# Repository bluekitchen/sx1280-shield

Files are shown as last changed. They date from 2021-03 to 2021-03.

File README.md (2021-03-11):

# SX1280 Breakout Board in Arduino Form-Factor

This is a breakout board for the SX1280 in Arduino form-factor to use with e.g. STM32 Nucleo Dev Boards or similar. It uses the [E28-2G4M12S module from EBYTE](https://www.ebyte.com/en/new-view-info.aspx?id=297), which is readily available from AliExpress or Banggod. 

## Motivation

The official SX1280 shield (SX1280RF1ZHP) from the Semtech's [SX1280DVK1ZHP](https://www.semtech.com/products/wireless-rf/24-ghz-transceivers/sx1280dvk1zhp) or [SX1280ED1ZHP](https://www.semtech.com/products/wireless-rf/lora-transceivers/sx1280ed1zhp) development kits have resistors in the SPI lines, which limit the SPI speed to about 5 Mhz. 

While SPI speed is not relevant for LoRa operations, implementing Bluetooth Low Energy requires to transfer data packets to/from the SX1280 quickly, which is easier to achieve with the max SPI speed of 18 Mhz. This breakout board was created to avoid replacing the resistors with 0 Ohm ones on the official shield and to allow the full 18 Mhz SPI speed.

## Usage

Signal | Arduino | Debug connector
-------|---------|----------------
3V3    |  3V3    | 
GND    |  GND    |   1
NSS    |  D7     |   2
SCK    |  SCK    |   3
MOSI   |  MOSI   |   4
MISO   |  MISO   |   5
BUSY   |  D3     |   6
DIO1   |  D5     |   7
DIO2   |         |   8
DIO3   |         |   9
nReset |  A0     |  10

All signals are provided at the J1 debug connector to hook up a logic analyzer.

The SX1280 can map various IRQ requests on the DIO1-3 pins. DIO1 is pre-assigned in this shield, while the DIO2 and DIO3 can be connected via jumper J2 to other GPIO pins if needed. 

Please note: The SX1280 is not 5V tolerant.

## References
- [SX1280 Product Page](https://www.semtech.com/products/wireless-rf/24-ghz-transceivers/sx1280)
- [SX1280 Datahsheet](https://semtech.my.salesforce.com/sfc/p/E0000000JelG/a/2R000000HoCW/8EVYKPLcthcKCB_cKzApAc6Xf6tAHtn9.UKcOh7SNmg)
- [28-2G4M12S Datasheet](https://www.ebyte.com/en/downpdf.aspx?id=286)

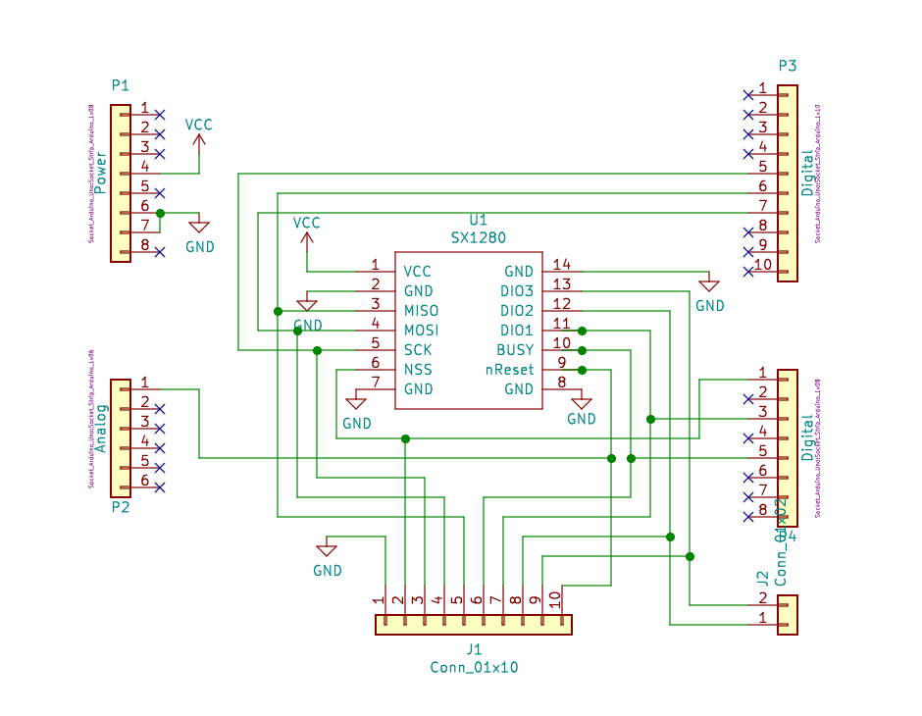
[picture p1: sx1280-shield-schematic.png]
Schematic

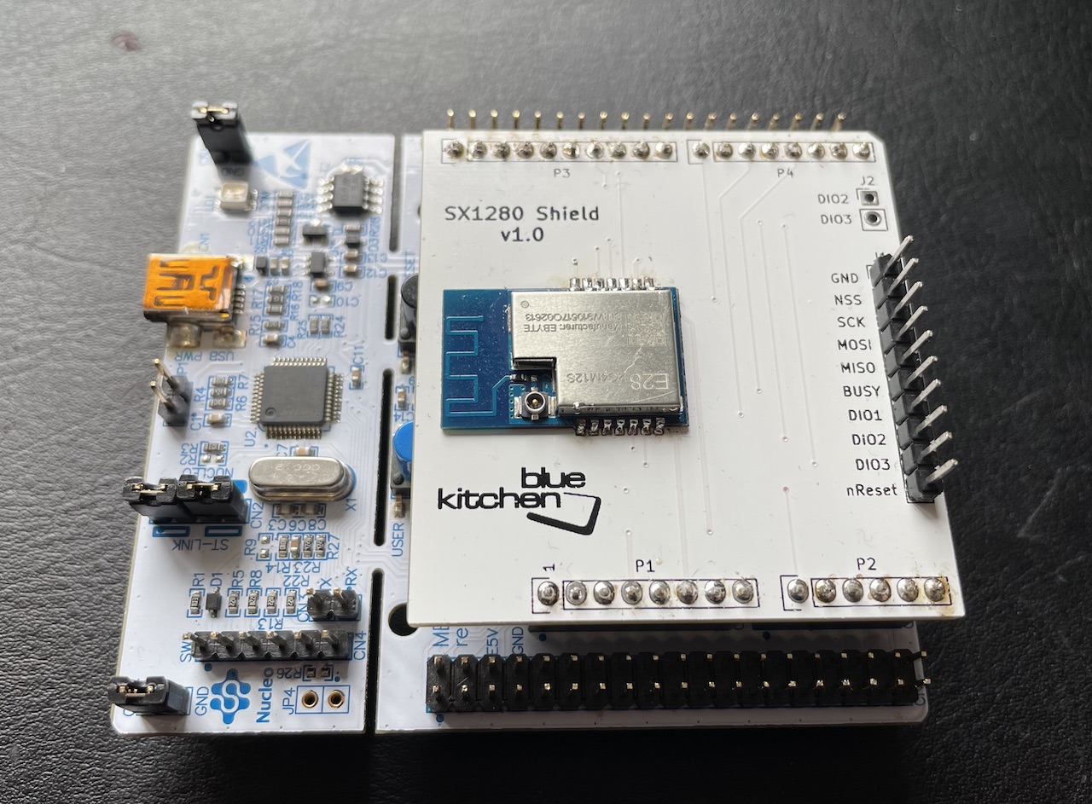
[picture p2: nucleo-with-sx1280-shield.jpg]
STM32 L476RG Nucleo with SX1280 Shield


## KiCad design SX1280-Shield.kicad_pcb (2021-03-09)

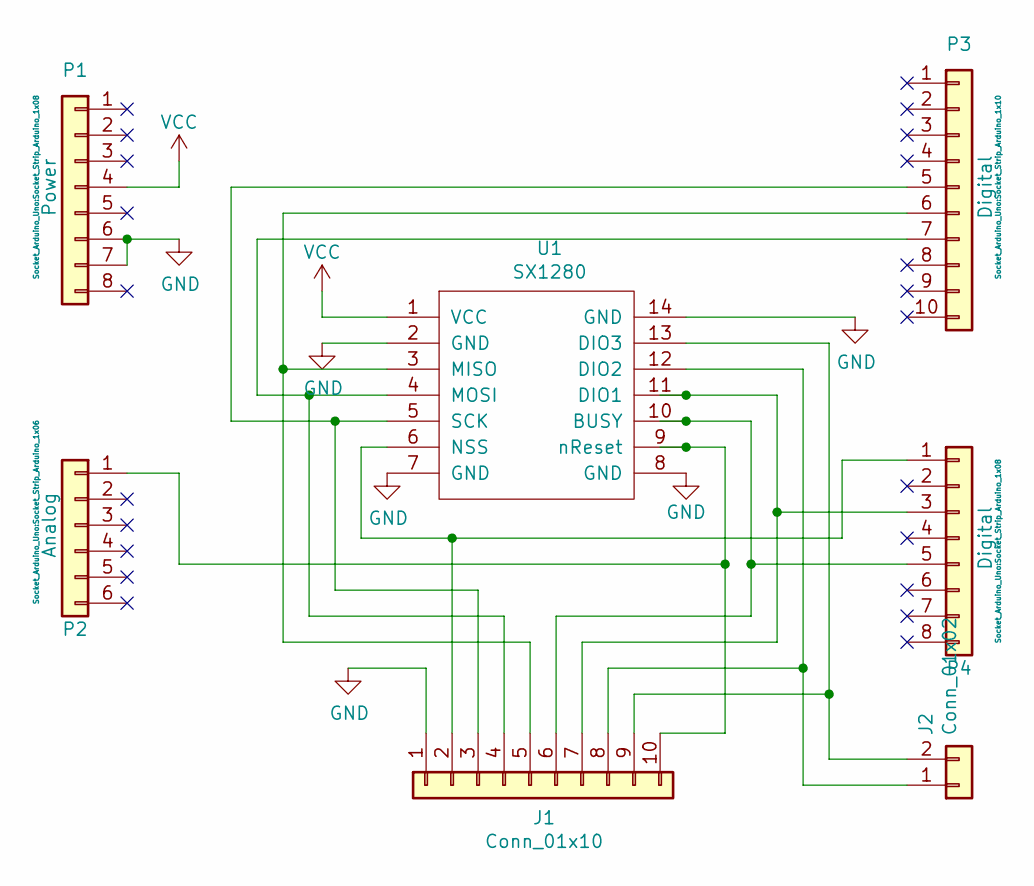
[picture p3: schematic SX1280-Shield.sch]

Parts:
J1: Conn_01x10; Socket_Strip_Arduino_1x10
J2: Conn_01x02; PinHeader_1x02_P2.54mm_Vertical
P1: Power; Socket_Strip_Arduino_1x08
P2: Analog; Socket_Strip_Arduino_1x06
P3: Digital; Socket_Strip_Arduino_1x10
P4: Digital; Socket_Strip_Arduino_1x08
U1: SX1280; E28-2G4M12S-SX1280

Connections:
GND: J1.1, P1.6, P1.7, U1.2 (GND), U1.7 (GND), U1.8 (GND), U1.14 (GND)
unnamed: J1.2, P4.1, U1.6 (NSS)
unnamed: J1.3, P3.5, U1.5 (SCK)
unnamed: J1.4, P3.7, U1.4 (MOSI)
unnamed: J1.5, P3.6, U1.3 (MISO)
unnamed: J1.6, P4.5, U1.10 (BUSY)
unnamed: J1.7, P4.3, U1.11 (DIO1)
unnamed: J1.8, J2.1, U1.12 (DIO2)
unnamed: J1.9, J2.2, U1.13 (DIO3)
unnamed: J1.10, P2.1, U1.9 (nReset)
VCC: P1.4, U1.1 (VCC)

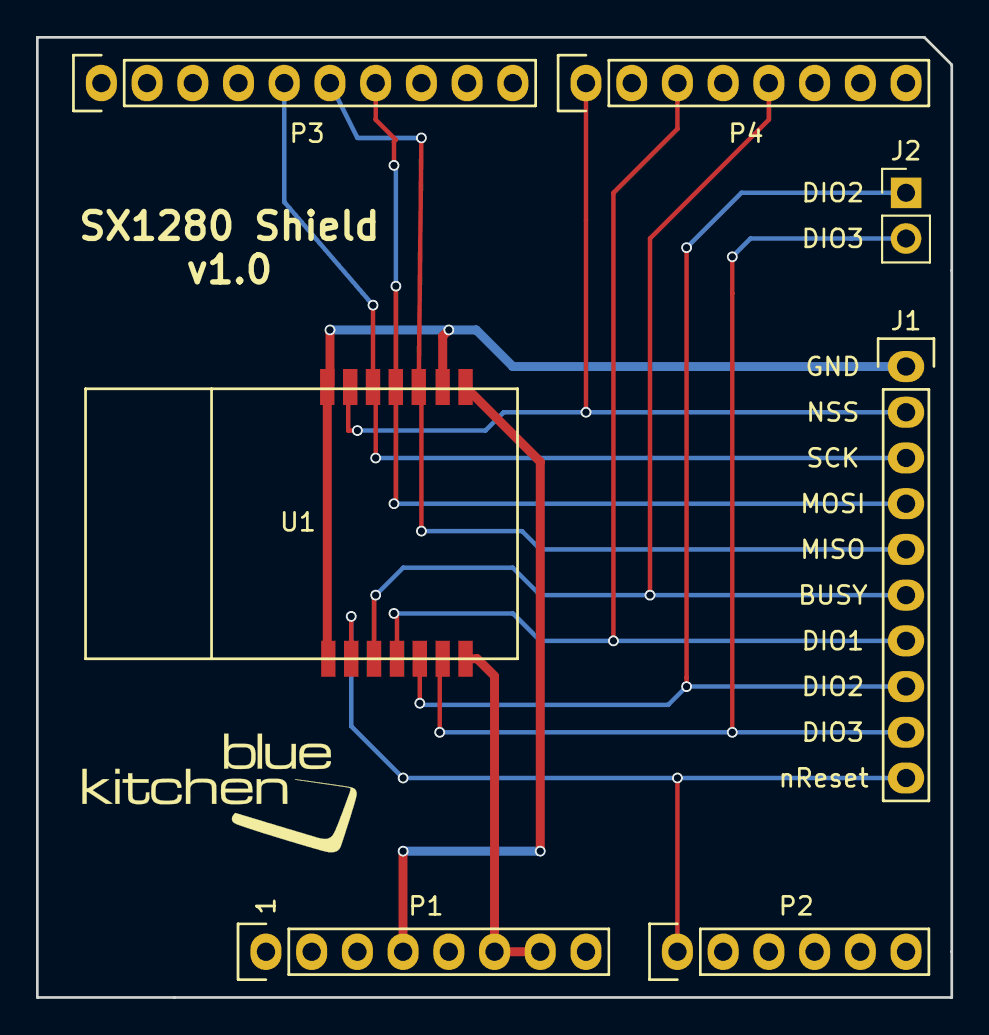
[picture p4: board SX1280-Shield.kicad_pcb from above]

Board: 2 copper layers, 50.8 x 53.3 mm, 7 parts (0 on the bottom side), 11 nets.
